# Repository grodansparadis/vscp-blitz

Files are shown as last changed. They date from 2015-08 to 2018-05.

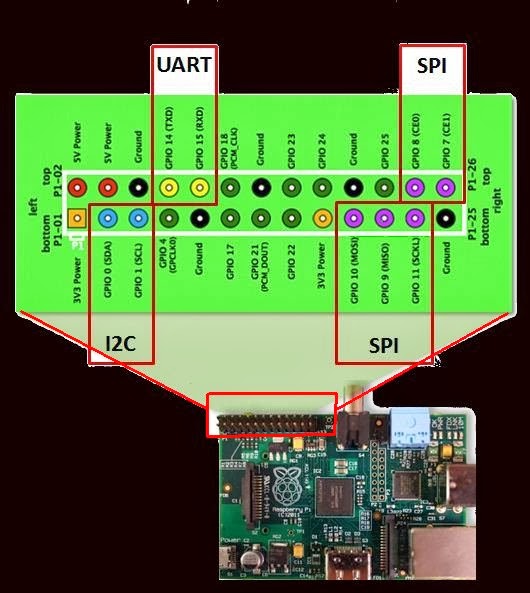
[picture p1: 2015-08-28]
docs/GPIO_pinout_raspberry_pi_v1.jpg

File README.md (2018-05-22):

# Blitz
Wifi + Ethernet + CAN board for VSCP

<hr>

This project is part of the <a href="http://www.vscp.org">VSCP (Very Simple Control Protocol) project</a>. 

<hr>

This project is licensed under the 
<a href="http://creativecommons.org/licenses/by-nc-sa/3.0/">Creative Commons open source license Attribution-NonCommercial-ShareAlike 3.0 Unported</a>. 
Other license options are available by conacting <a href="malto:info@grodansparadis.com">Paradis of the Frog AB</a>

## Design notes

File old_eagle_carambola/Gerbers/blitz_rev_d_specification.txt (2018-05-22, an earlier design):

Ake Hedman <akhe@grodansparadis.com>
Grodans Paradis AB

Date:				2014-06-18
Part Number: 		Blitz
Number of boards: 	120
Number of layers: 	2
Material: 			FR4
Final Thickness:	1.6 mm
Final copper:		1/1oz
Surface treatment: 	ENIG
Unit Size:			72x110
Panel Size:		
Unit/panel:			4
Solder Mask:		Black
Silk Screen: 		White	
Outline Profile:	CNC Routing + V-cut
X-out Allowed:		1
Stencil needed:		yes
Gerber layer for Stencil: Component Cream (pmc)

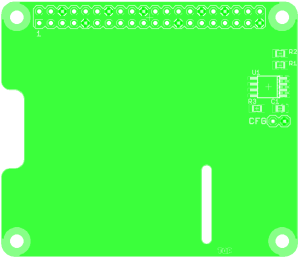
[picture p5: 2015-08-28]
docs/RasPi-BplusHAT.png

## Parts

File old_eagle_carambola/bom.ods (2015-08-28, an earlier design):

Partl | ist exported from C:/U | sers/akhe/Documents/d | evelopment/hardware | _zeus/wifi/carambola/blitz/eagle/blitz.sch at 2011-10-05 18:25:48
Part | Value | Device | Package | Description | Description | Supplier | Partnumber | Price
C1 | 4.7nF | C-EUC0805 | C0805 | CAPACITOR, European symbol | 4.7nF Cheramic capacitor | Bejoken | 522508 | 0,05
C2 | 4.7nF | C-EUC0805 | C0805 | CAPACITOR, European symbol | 4.7nF Cheramic capacitor | Bejoken | 522508 | 0,05
C3 | 2.2UF 50V | C-EUC2012 | C2012 | CAPACITOR, European symbol | Capacity | Digikey | 445-3464-1-ND | 2,4
C4 | 220uF/10V | CPOL-EUSMCC | SMC_C | POLARIZED CAPACITOR, European symbol | Capacitor SMD | Digikey | 399-5168-1-nd | 12,56
C5 | 220uF/10V | CPOL-EUSMCC | SMC_C | POLARIZED CAPACITOR, European symbol | Capacitor SMD | Digikey | 399-5168-1-nd | 12,56
C6 | 100n | C-EUC0805 | C0805 | CAPACITOR, European symbol | 100nF Cheramic capacitor | Bejoken | 522526 | 0,07
C7 | 100n | C-EUC0805 | C0805 | CAPACITOR, European symbol | 100nF Cheramic capacitor | Bejoken | 522526 | 0,07
C8 | 15pF | C-EUC0805 | C0805 | CAPACITOR, European symbol | Kondensator | Bejoken | 522419 | 0,11
C9 | 15pF | C-EUC0805 | C0805 | CAPACITOR, European symbol | Kondensator | Bejoken | 522419 | 0,11
C10 | 100nF | C-EUC0805 | C0805 | CAPACITOR, European symbol | Avkopplingskondensator | Bejoken | 522526 | 0,07
C11 | 100nF | C-EUC0805 | C0805 | CAPACITOR, European symbol | Avkopplingskondensator | Bejoken | 522526 | 0,07
C12 | 100nF | C-EUC0805 | C0805 | CAPACITOR, European symbol | Avkopplingskondensator | Bejoken | 522526 | 0,07
C13 | 22pF | C-EUC0805 | C0805 | CAPACITOR, European symbol | 22pF Cheramic capacitor | Bejoken | 522423 | 0,11
C14 | 22pF | C-EUC0805 | C0805 | CAPACITOR, European symbol | 22pF Cheramic capacitor | Bejoken | 522423 | 0,11
C15 | 100n | C-EUC0805 | C0805 | CAPACITOR, European symbol | 100nF Cheramic capacitor | Bejoken | 522526 | 0,07
C16 | 4.7nF | C-EUC0805 | C0805 | CAPACITOR, European symbol | 4.7nF Cheramic capacitor | Bejoken | 522508 | 0,05
C17 | 4.7nF | C-EUC0805 | C0805 | CAPACITOR, European symbol | 4.7nF Cheramic capacitor | Bejoken | 522508 | 0,05
C18 | 2.2UF 50V | C-EUC2012 | C2012 | CAPACITOR, European symbol | Capacity | Digikey | 445-3464-1-ND | 2,4
C19 | 220uF/10V | CPOL-EUSMCC | SMC_C | POLARIZED CAPACITOR, European symbol | Capacitor SMD | Digikey | 399-5168-1-nd | 12,56
C20 | 220uF/10V | CPOL-EUSMCC | SMC_C | POLARIZED CAPACITOR, European symbol | Capacitor SMD | Digikey | 399-5168-1-nd | 12,56
C21 | 100nF | C-EUC0805 | C0805 | CAPACITOR, European symbol | Avkopplingskondensator | Bejoken | 522526 | 0,07
C22 | 100nF | C-EUC0805 | C0805 | CAPACITOR, European symbol | Avkopplingskondensator | Bejoken | 522526 | 0,07
C23 | 100n | C-EUC0805 | C0805 | CAPACITOR, European symbol | 100nF Cheramic capacitor | Bejoken | 522526 | 0,07
C24 | 100n | C-EUC0805 | C0805 | CAPACITOR, European symbol | 100nF Cheramic capacitor | Bejoken | 522526 | 0,07
C25 | 100n | C-EUC0805 | C0805 | CAPACITOR, European symbol | 100nF Cheramic capacitor | Bejoken | 522526 | 0,07
C26 | 2.2uF | C-EUC2012 | C2012 | CAPACITOR, European symbol | Capacitor | Digikey | 445-3464-1-ND | 2,4
C27 | 100n | C-EUC0805 | C0805 | CAPACITOR, European symbol | 100nF Cheramic capacitor | Bejoken | 522526 | 0,07
C28 | 100n | C-EUC0805 | C0805 | CAPACITOR, European symbol | 100nF Cheramic capacitor | Bejoken | 522526 | 0,07
C29 | 100n | C-EUC0805 | C0805 | CAPACITOR, European symbol | 100nF Cheramic capacitor | Bejoken | 522526 | 0,07
D1 | 1N5819 | 1N5819 | SOD-123 |  | Schotty diod | Digikey | 1n5819hw-fdict-nd | 3,84
D2 | NUP2105L | DIODE-2CA|ACSOT23 | SOT23 | Dual DIODE Cathode-Anode|Anode-Cathode | Tansient protection | Digikey | NUP2105LT1GOSCT-ND | 4
D3 | LED yellow | LED_2012 | C2012 |  | Gul LED | Digikey | 475-1410-1-nd | 0,88
D4 | LED Green | LED_2012 | C2012 |  | Grön LED | Digikey | 475-1410-1-nd | 0,88
D5 | 1N5819 | 1N5819 | SOD-123 |  | Schotty diod | Digikey | 1n5819hw-fdict-nd | 3,84
D6 | LED Red | LED_2012 | C2012 |  | LED röd | Digikey | 475-1415-1-ND | 0,88
H1 | Antenna | SPECIAL_DRILL_0.1000 | PAD_0.1000 | Special drills |  |  |  | 0
IC1 | BD9001F | BD9001F | SOP8 |  | Swithing regulator | Digikey | BD9001F-E2CT-ND | 39,84
IC2 | MCP2515 | MCP2515 | SO-18W |  | CAN Controller | Digikey | MCP2515-I/SO-ND | 15,84
IC3 | SN65HVD232 | MCP2551SN | SO-08 | High Speed CAN tranceiver | 3.3V CAN tranceiver | Digikey | 296-15381-1-ND | 26,05
IC4 | BD9001F | BD9001F | SOP8 |  | Swithing regulator | Digikey | BD9001F-E2CT-ND | 39,84
IC5 | PIC18F26K20 | PIC18F26K20 | SSOP28 |  | Processor | Digikey | PIC18F26K20-I/SS-ND | 20,98
IC6 | 11AA02E48 | 11AA02E48 | SOT23 |  | MAC Address | Digikey | 11aa02e48t-i/ttct-nd | 4
IC7 | 11AA02E48 | 11AA02E48 | SOT23 |  | MAC Address | Digikey | 11aa02e48t-i/ttct-nd | 4
IC8 | CARAMBOLA | CARAMBOLA | CARAMBOLA |  | Linux ;odule | 8Devices | x1 | 200
J1 | 22-23-2021 | 22-23-2021 | 22-23-2021 | .100" (2.54mm) Center Header - 2 Pin | Enkel stiftlist | Digikey | SAM1035-50-ND | 0,33
J2 | A00-108-220-450 | A00-108-220-450 | RJ-45 |  | RJ-45 connector | Digikey | 151-1099-nd | 5,6
J3 | MICROSD_SPI_MODE | MICROSD_SPI_MODE | MICRO_SD_CONNECTOR | MOLEX - 49225-0821 - CONNECTEUR MICRO SD PUSH/PUSH REVFabricant: MOLEXCode commande Farnell: 1366700Référence fabricant: 49225-0821 | SD Connector | Digikey | WM3295ct-ND | 33,36
J4 | USB-B-S | USB-B-S | USB-B-SMT | USB Connectors | USB B connector | Digikey | ED2994-ND | 8,8
J5 |  | MA03-1 | MA03-1 | PIN HEADER | Enkel stiftlist | Digikey | SAM1035-50-ND | 0,33
J6 |  | MA03-1 | MA03-1 | PIN HEADER | Enkel stiftlist | Digikey | SAM1035-50-ND | 0,33
J7 |  | MA08-1 | MA08-1 | PIN HEADER | Enkel Stiftlist | Digikey | SAM1035-50-ND | 0,33
J8 | TAIMAGRPJ-003TC1 | TAIMAGRPJ-003TC1 | TAIMAGRJP-003TC1 |  | Ethernet Trafo | Tysk | RPC | 40
JP2 | TX433_3V_MODULE | TX433_3V_MODULE | FOUR |  | Transmitter 433MHz | Electrokit | 41004048 | 44,5
JP4 | Programming connector | MA06-1 | MA06-1 | PIN HEADER | Enkel stiftlist | Digikey | SAM1035-50-ND | 0,33
L1 | NR10050T470M | NR10050T470M | NR10050T470M |  | Inductance | Digikey | 587-1700-1-ND | 7,52
L2 | NR10050T470M | NR10050T470M | NR10050T470M |  | Inductance | Digikey | 587-1700-1-ND | 7,52
L3 | FERRITE-BEAD | FERRITE-BEAD | 805 |  | Ferrite | Digikey | 445-1568-1-nd | 2,88
Q1 | 12 MHZ | HC-49S | 9C | Digikey 887-1050-1-nd | Crystal | Digikey | 887-1053-1-ND | 2,56
R1 | 150k | R-EU_M0805 | M0805 | RESISTOR, European symbol | Resistor | Bejoken | 454710 | 0,01
R2 | 150k | R-EU_M0805 | M0805 | RESISTOR, European symbol | Resistor | Bejoken | 454710 | 0,01
R3 | 39k/1% | R-EU_M0805 | M0805 | RESISTOR, European symbol | Resistor | Bejoken | 454690 | 0,01
R4 | 10K/1% | R-EU_M0805 | M0805 | RESISTOR, European symbol | Resistor | Bejoken | 454676 | 0,01
R5 | 330 | R-EU_M0805 | M0805 | RESISTOR, European symbol | Resistor | Bejoken | 454636 | 0,01
R6 | 10k | R-EU_M0805 | M0805 | RESISTOR, European symbol | Resistor | Bejoken | 454676 | 0,01
R9 | 10K | R-EU_R0805 | R0805 | RESISTOR, European symbol | Resistor | Bejoken | 454676 | 0,01
R10 | 10K | R-EU_R0805 | R0805 | RESISTOR, European symbol | Resistor | Bejoken | 454676 | 0,01
R11 | 150k | R-EU_M0805 | M0805 | RESISTOR, European symbol | Resistor | Bejoken | 454710 | 0,01
R12 | 150k | R-EU_M0805 | M0805 | RESISTOR, European symbol | Resistor | Bejoken | 454710 | 0,01
R13 | 4.3k/1% | R-EU_M0805 | M0805 | RESISTOR, European symbol | Resistor | Digikey | 311-4.30KCRTR-ND | 0,02
R14 | 1.8K/1% | R-EU_M0805 | M0805 | RESISTOR, European symbol | Resistor | Bejoken | 454658 | 0,01
R15 | 49.9/1% | R-EU_M0805 | M0805 | RESISTOR, European symbol | Resistor | Digikey | 311-49.9CRTR-ND | 0,02
R16 | 49.9/1% | R-EU_M0805 | M0805 | RESISTOR, European symbol | Resistor | Digikey | 311-49.9CRTR-ND | 0,02
R17 | 49.9/1% | R-EU_M0805 | M0805 | RESISTOR, European symbol | Resistor | Digikey | 311-49.9CRTR-ND | 0,02
R18 | 49.9/1% | R-EU_M0805 | M0805 | RESISTOR, European symbol | Resistor | Digikey | 311-49.9CRTR-ND | 0,02
R19 | 120r | R-EU_R0805 | R0805 | RESISTOR, European symbol | Resistor | Bejoken | 454626 | 0,01
R20 | 1M | R-EU_M0805 | M0805 | RESISTOR, European symbol | Resistor | Bejoken | 454742 | 0,01
R21 | 330 | R-EU_M0805 | M0805 | RESISTOR, European symbol | Resistor | Bejoken | 454636 | 0,01
R22 | 330 | R-EU_M0805 | M0805 | RESISTOR, European symbol | Resistor | Bejoken | 454636 | 0,01
R23 | 10k | R-EU_M0805 | M0805 | RESISTOR, European symbol | Resistor | Bejoken | 454676 | 0,01
R24 | 330 | R-EU_M0805 | M0805 | RESISTOR, European symbol | Resistor | Bejoken | 454636 | 0,01
X1 | TXC-7V-SERIES 8 MHz | TXC-7V-SERIES | TXC-7V-SERIES |  | Kristall | Digokey | 887-1452-1-nd | 8,18
Z1 | 1N4731(4.3V) | 1N4731(4.3V) | 1N4731 |  | Zener | Digikey | 1n4731A-tpct-nd | 3,6
Z2 | 1N4731(4.3V) | 1N4731(4.3V) | 1N4731 |  | Zener | Digikey | 1n4731A-tpct-nd | 3,6
 |  |  |  |  |  |  |  | 594,02

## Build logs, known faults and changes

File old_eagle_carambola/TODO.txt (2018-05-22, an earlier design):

Add PoE Ag9400 - https://www.semiconductorstore.com/pages/asp/DownloadDirect.asp?sid=1401505158572

Add Power connector instead of SD card.

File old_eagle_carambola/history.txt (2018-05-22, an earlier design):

Blitz
=====

2014-06-04 - AKHE Fixed dimensions.
2014-06-04 - AKHE Ready for factory
2014-06-04 - AKHE Rev D
2014-04-11 - AKHE Changed crystal to 10MHz

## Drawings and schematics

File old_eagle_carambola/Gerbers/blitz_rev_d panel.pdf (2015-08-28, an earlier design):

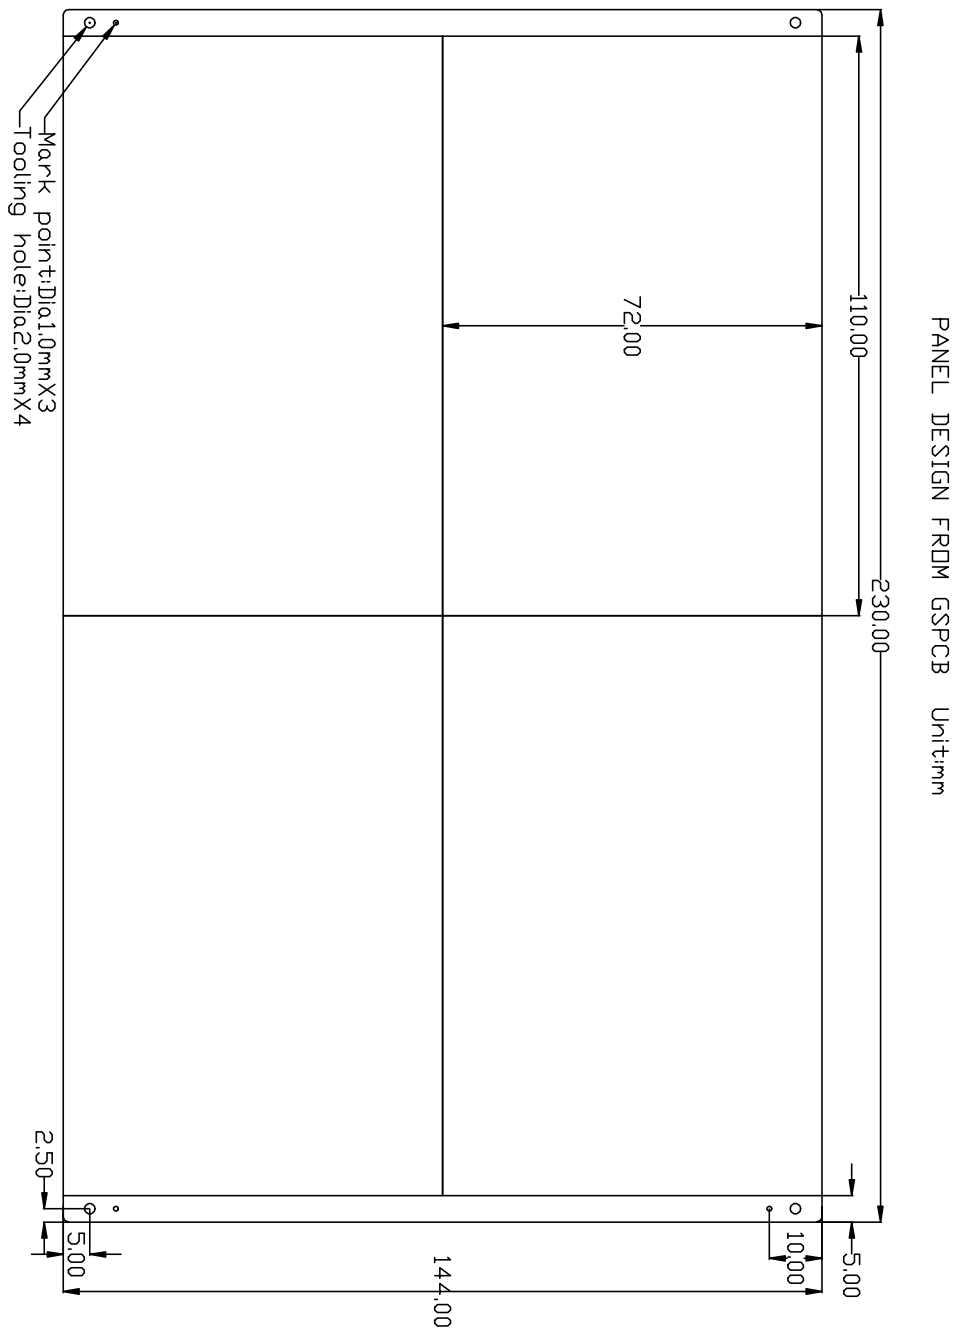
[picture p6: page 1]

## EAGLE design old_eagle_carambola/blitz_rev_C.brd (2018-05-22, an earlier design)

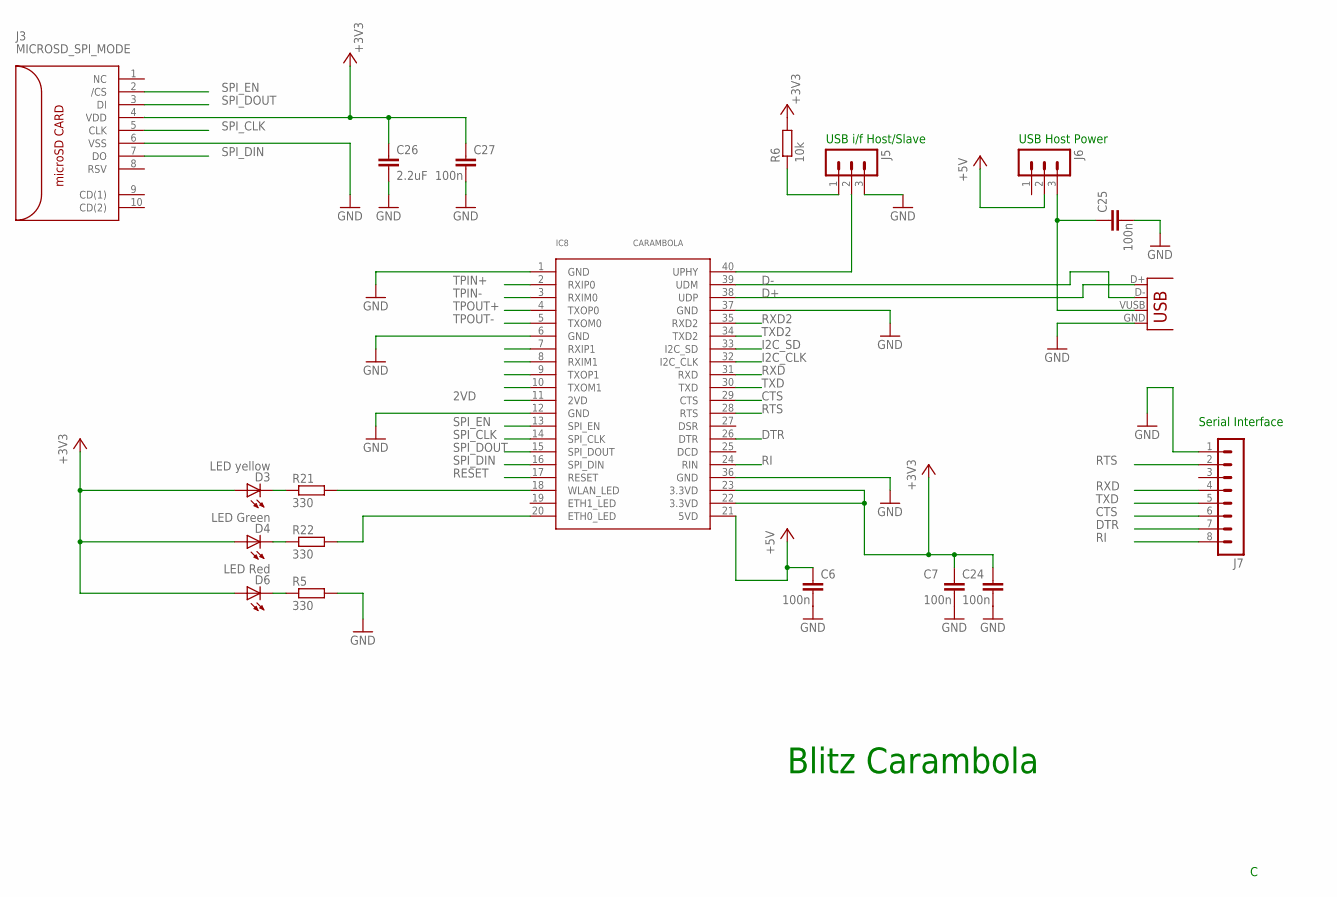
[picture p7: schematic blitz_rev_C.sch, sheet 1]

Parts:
C6, C7, C24, C25, C27: 100n; C0805
C26: 2.2uF; C2012
D3: LED yellow; C2012
D4: LED Green; C2012
D6: LED Red; C2012
IC8: CARAMBOLA
J3: MICROSD_SPI_MODE; MICRO_SD_CONNECTOR
J4: USB-B-S; USB-B-SMT
J5, J6: MA03-1
J7: MA08-1
R5, R21, R22: 330; M0805
R6: 10k; M0805

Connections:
2VD: IC8.11 (2VD)
+3V3: C7.1, C24.1, C26.1, C27.1, D3.1 (A), D4.1 (A), D6.1 (A), IC8.22 (3.3VD), IC8.23 (3.3VD), J3.4 (VDD), R6.2; also elsewhere on the board
+5V: C6.1, IC8.21 (5VD), J6.2; also elsewhere on the board
CTS: IC8.29 (CTS), J7.6
D+: IC8.38 (UDP), J4.D+
D-: IC8.39 (UDM), J4.D-
DTR: IC8.26 (DTR), J7.7
GND: C6.2, C7.2, C24.2, C25.2, C26.2, C27.2, IC8.1 (GND), IC8.6 (GND), IC8.12 (GND), IC8.36 (GND), IC8.37 (GND), J3.6 (VSS), J4.GND, J5.3, J7.1, R5.2; also elsewhere on the board
I2C_CLK: IC8.32 (I2C_CLK)
I2C_SD: IC8.33 (I2C_SD)
unnamed: J5.1, R6.1
unnamed: C25.1, J4.VUSB (VBUS), J6.3
unnamed: D4.2 (C), R22.1
unnamed: D3.2 (C), R21.1
unnamed: IC8.18 (WLAN_LED), R21.2
unnamed: IC8.20 (ETH0_LED), R22.2
unnamed: D6.2 (C), R5.1
unnamed: IC8.40 (UPHY), J5.2
RESET: IC8.17 (RESET)
RI: IC8.24 (RIN), J7.8
RTS: IC8.28 (RTS), J7.2
RXD: IC8.31 (RXD), J7.4
RXD2: IC8.35 (RXD2); also elsewhere on the board
SPI_CLK: IC8.14 (SPI_CLK), J3.5 (CLK)
SPI_DIN: IC8.16 (SPI_DIN), J3.7 (DO)
SPI_DOUT: IC8.15 (SPI_DOUT), J3.3 (DI)
SPI_EN: IC8.13 (SPI_EN), J3.2 (/CS)
TPIN+: IC8.2 (RXIP0); also elsewhere on the board
TPIN-: IC8.3 (RXIM0); also elsewhere on the board
TPOUT+: IC8.4 (TXOP0); also elsewhere on the board
TPOUT-: IC8.5 (TXOM0); also elsewhere on the board
TXD: IC8.30 (TXD), J7.5
TXD2: IC8.34 (TXD2); also elsewhere on the board

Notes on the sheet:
Blitz Carambola
USB i/f Host/Slave
USB Host Power
Serial Interface

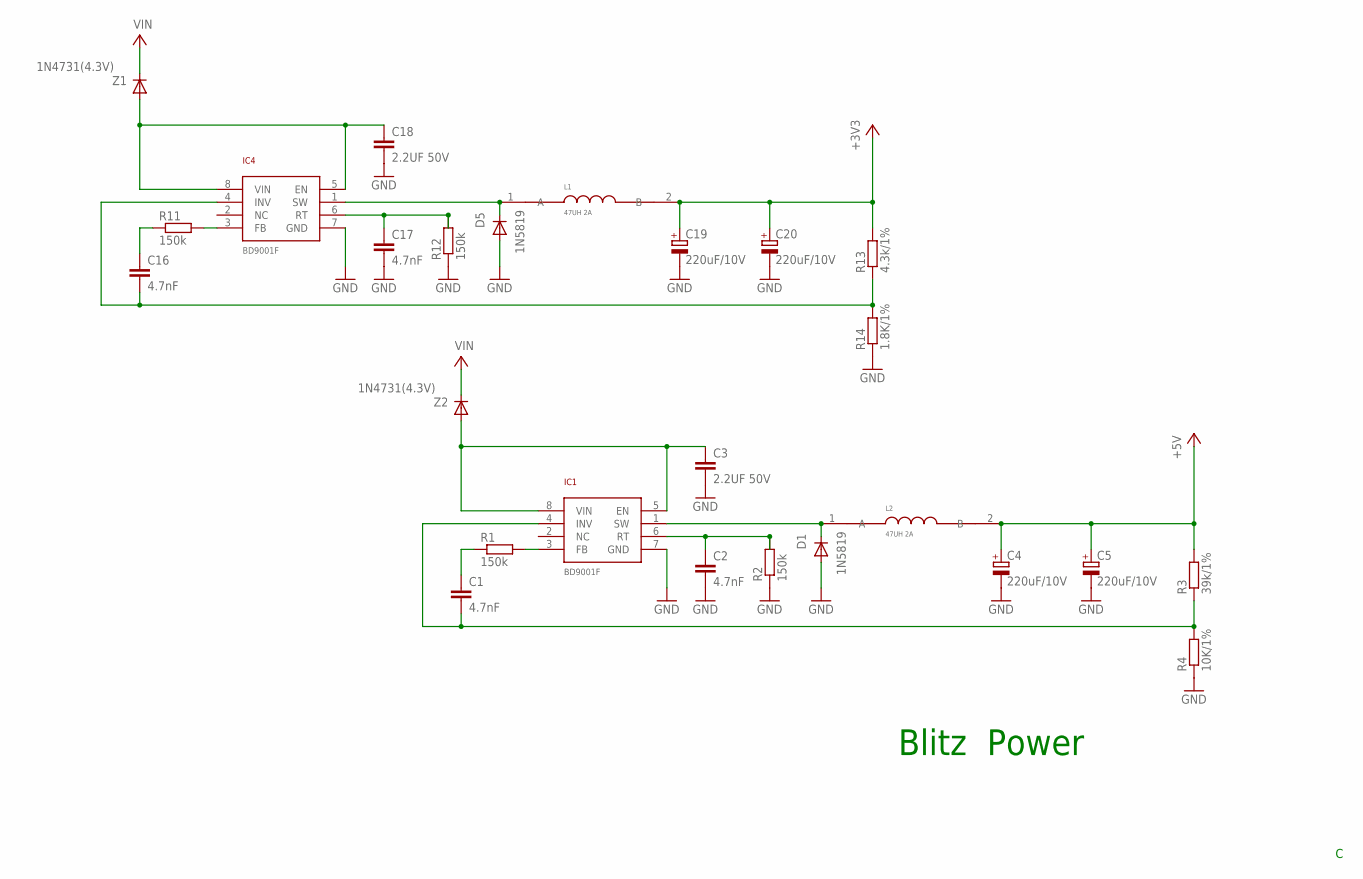
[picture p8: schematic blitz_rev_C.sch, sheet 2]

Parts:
C1, C2, C16, C17: 4.7nF; C0805
C3, C18: 2.2UF 50V; C2012
C4, C5, C19, C20: 220uF/10V; SMC_C
D1, D5: 1N5819; SOD-123
IC1, IC4: BD9001F; SOP8
L1, L2: 47UH 2A; NR10050T470M
R1, R2, R11, R12: 150k; M0805
R3: 39k/1%; M0805
R4: 10K/1%; M0805
R13: 4.3k/1%; M0805
R14: 1.8K/1%; M0805
Z1, Z2: 1N4731(4.3V); 1N4731

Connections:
+3V3: C19.+, C20.+, L1.2 (B), R13.2; also elsewhere on the board
+5V: C4.+, C5.+, L2.2 (B), R3.2; also elsewhere on the board
GND: C2.2, C3.2, C4.-, C5.-, C17.2, C18.2, C19.-, C20.-, D1.A, D5.A, IC1.7 (GND), IC4.7 (GND), R2.1, R4.1, R12.1, R14.1; also elsewhere on the board
unnamed: IC1.3 (FB), R1.2
unnamed: C1.1, R1.1
unnamed: C1.2, IC1.4 (INV), R3.1, R4.2
unnamed: C2.1, IC1.6 (RT), R2.2
unnamed: C3.1, IC1.5 (EN), IC1.8 (VIN), Z2.A
unnamed: D1.C, IC1.1 (SW), L2.1 (A)
unnamed: IC4.3 (FB), R11.2
unnamed: C16.1, R11.1
unnamed: C16.2, IC4.4 (INV), R13.1, R14.2
unnamed: C17.1, IC4.6 (RT), R12.2
unnamed: C18.1, IC4.5 (EN), IC4.8 (VIN), Z1.A
unnamed: D5.C, IC4.1 (SW), L1.1 (A)
V+: Z1.C, Z2.C; also elsewhere on the board

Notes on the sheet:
Blitz Power

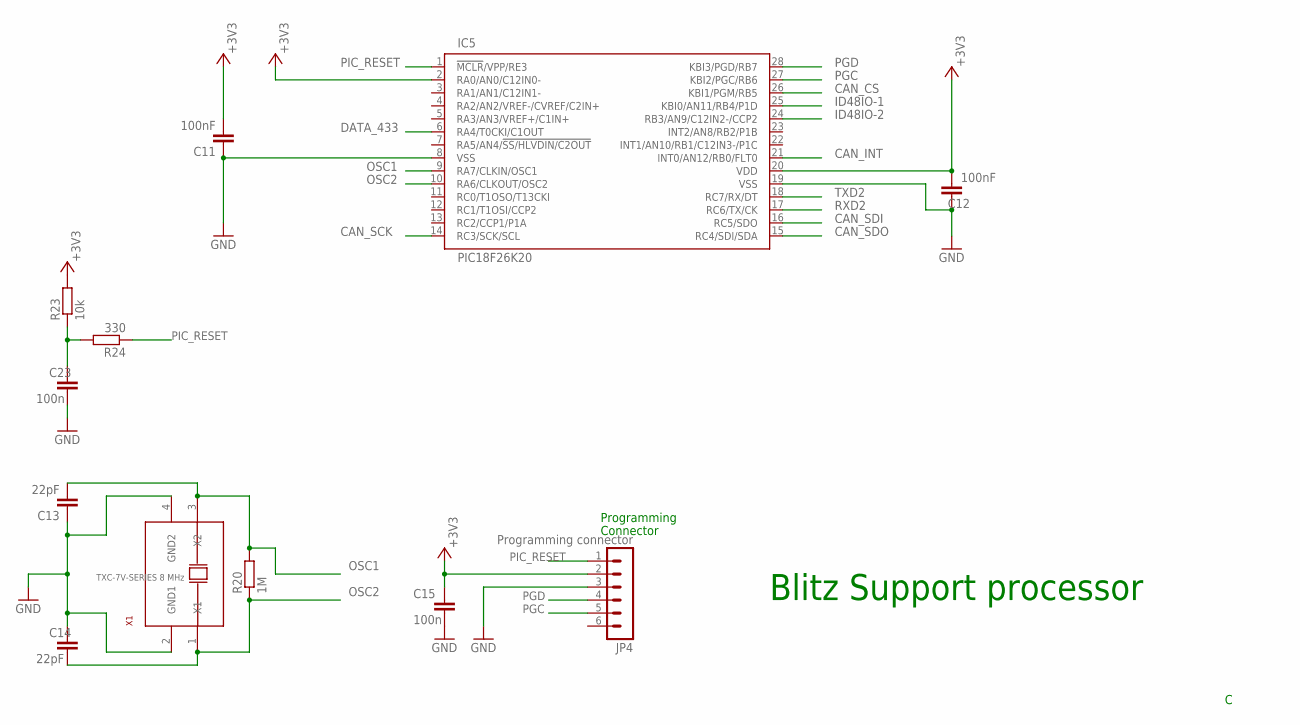
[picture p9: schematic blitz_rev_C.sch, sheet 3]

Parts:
C11, C12: 100nF; C0805
C13, C14: 22pF; C0805
C15, C23: 100n; C0805
IC5: PIC18F26K20; SSOP28
JP4: Programming connector; MA06-1
R20: 1M; M0805
R23: 10k; M0805
R24: 330; M0805
X1: TXC-7V-SERIES 8 MHz; TXC-7V-SERIES

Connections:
+3V3: C11.2, C12.2, C15.1, IC5.2 (RA0/AN0/C12IN0-), IC5.20 (VDD), JP4.2, R23.2; also elsewhere on the board
CAN_CS: IC5.26 (KBI1/PGM/RB5); also elsewhere on the board
CAN_INT: IC5.21 (INT0/AN12/RB0/FLT0); also elsewhere on the board
CAN_SCK: IC5.14 (RC3/SCK/SCL); also elsewhere on the board
CAN_SDI: IC5.16 (RC5/SDO); also elsewhere on the board
CAN_SDO: IC5.15 (RC4/SDI/SDA); also elsewhere on the board
DATA_433: IC5.6 (RA4/T0CKI/C1OUT); also elsewhere on the board
GND: C11.1, C12.1, C13.1, C14.1, C15.2, C23.2, IC5.8 (VSS), IC5.19 (VSS), JP4.3, X1.2 (GND1), X1.4 (GND2); also elsewhere on the board
ID48IO-1: IC5.25 (KBI0/AN11/RB4/P1D); also elsewhere on the board
ID48IO-2: IC5.24 (RB3/AN9/C12IN2-/CCP2); also elsewhere on the board
unnamed: C23.1, R23.1, R24.2
OSC1: C13.2, IC5.9 (RA7/CLKIN/OSC1), R20.2, X1.3 (X2)
OSC2: C14.2, IC5.10 (RA6/CLKOUT/OSC2), R20.1, X1.1 (X1)
PGC: IC5.27 (KBI2/PGC/RB6), JP4.5
PGD: IC5.28 (KBI3/PGD/RB7), JP4.4
PIC_RESET: IC5.1 (!MCLR!/VPP/RE3), JP4.1, R24.1
RXD2: IC5.17 (RC6/TX/CK); also elsewhere on the board
TXD2: IC5.18 (RC7/RX/DT); also elsewhere on the board

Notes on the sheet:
Programming
Connector
Blitz Support processor

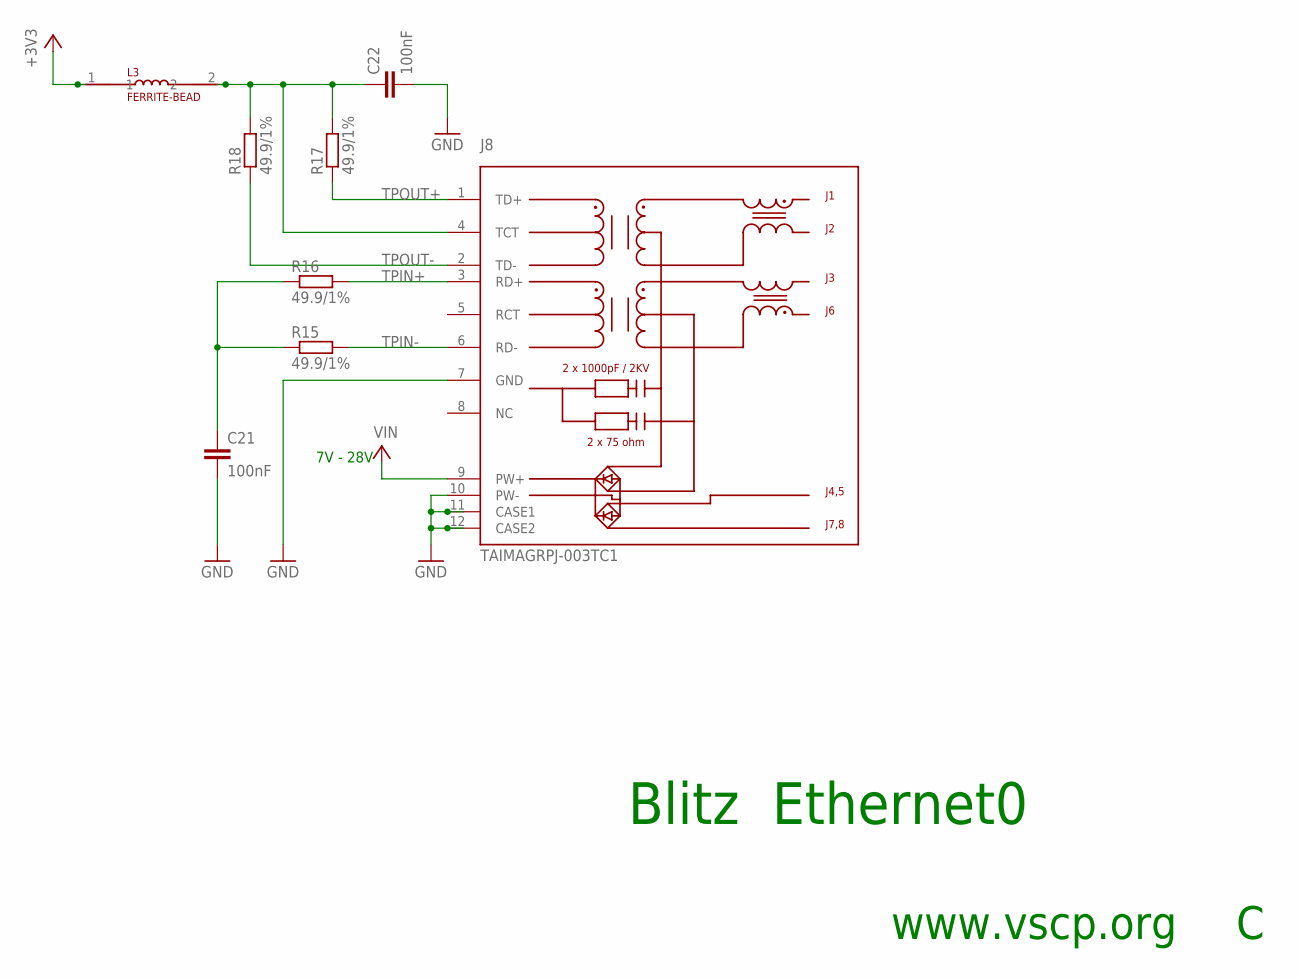
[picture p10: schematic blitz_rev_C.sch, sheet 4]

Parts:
C21, C22: 100nF; C0805
J8: TAIMAGRPJ-003TC1; TAIMAGRJP-003TC1
L3: FERRITE-BEAD; 0805
R15, R16, R17, R18: 49.9/1%; M0805

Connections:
+3V3: L3.1; also elsewhere on the board
GND: C21.2, C22.2, J8.7 (GND), J8.10 (PW-), J8.11 (CASE1), J8.12 (CASE2); also elsewhere on the board
unnamed: C21.1, R15.1, R16.1
unnamed: C22.1, J8.4 (TCT), L3.2, R17.2, R18.2
TPIN+: J8.3 (RD+), R16.2; also elsewhere on the board
TPIN-: J8.6 (RD-), R15.2; also elsewhere on the board
TPOUT+: J8.1 (TD+), R17.1; also elsewhere on the board
TPOUT-: J8.2 (TD-), R18.1; also elsewhere on the board
V+: J8.9 (PW+); also elsewhere on the board

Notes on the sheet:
Blitz Ethernet0
7V - 28V
www.vscp.org

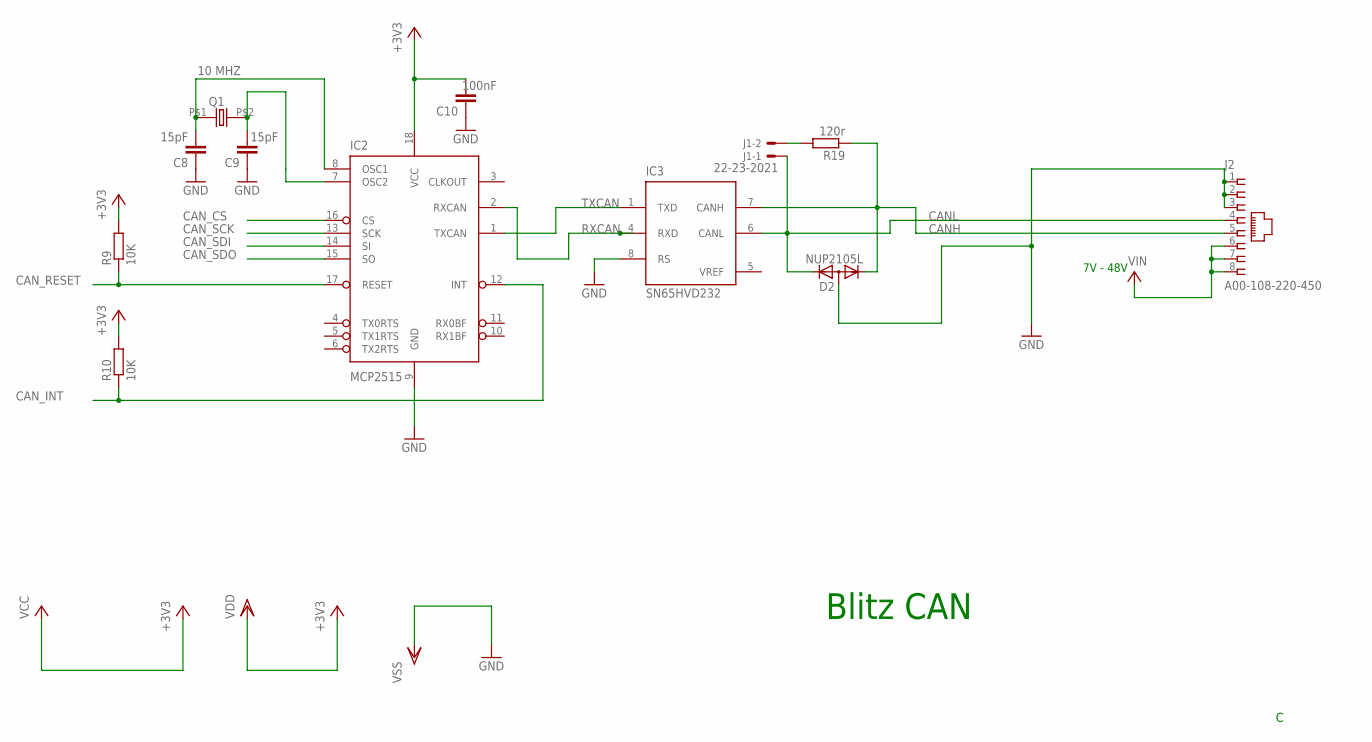
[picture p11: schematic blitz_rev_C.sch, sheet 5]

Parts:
C8, C9: 15pF; C0805
C10: 100nF; C0805
D2: NUP2105L; SOT23
IC2: MCP2515; SO-18W
IC3: SN65HVD232; SO-08
J1: 22-23-2021
J2: A00-108-220-450; RJ-45
Q1: 10 MHZ; 9C
R9, R10: 10K; R0805
R19: 120r; R0805

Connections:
+3V3: C10.2, IC2.18 (VCC), IC3.3 (VDD), R9.2, R10.2; also elsewhere on the board
CANH: D2.1 (K1), IC3.7 (CANH), J2.5, R19.1
CANL: D2.2 (K2), IC3.6 (CANL), J1.1, J2.4
CAN_CS: IC2.16 (CS); also elsewhere on the board
CAN_INT: IC2.12 (INT), R10.1; also elsewhere on the board
CAN_RESET: IC2.17 (RESET), R9.1
CAN_SCK: IC2.13 (SCK); also elsewhere on the board
CAN_SDI: IC2.14 (SI); also elsewhere on the board
CAN_SDO: IC2.15 (SO); also elsewhere on the board
GND: C8.1, C9.1, C10.1, D2.3 (A), IC2.9 (GND), IC3.2 (VSS), IC3.8 (RS), J2.1, J2.2, J2.3; also elsewhere on the board
unnamed: C8.2, IC2.8 (OSC1), Q1.P$1 (1)
unnamed: C9.2, IC2.7 (OSC2), Q1.P$2 (2)
unnamed: J1.2, R19.2
RXCAN: IC2.2 (RXCAN), IC3.4 (RXD)
TXCAN: IC2.1 (TXCAN), IC3.1 (TXD)
V+: J2.6, J2.7, J2.8; also elsewhere on the board
VREF: IC3.5 (VREF)

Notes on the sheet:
Blitz CAN
7V - 48V

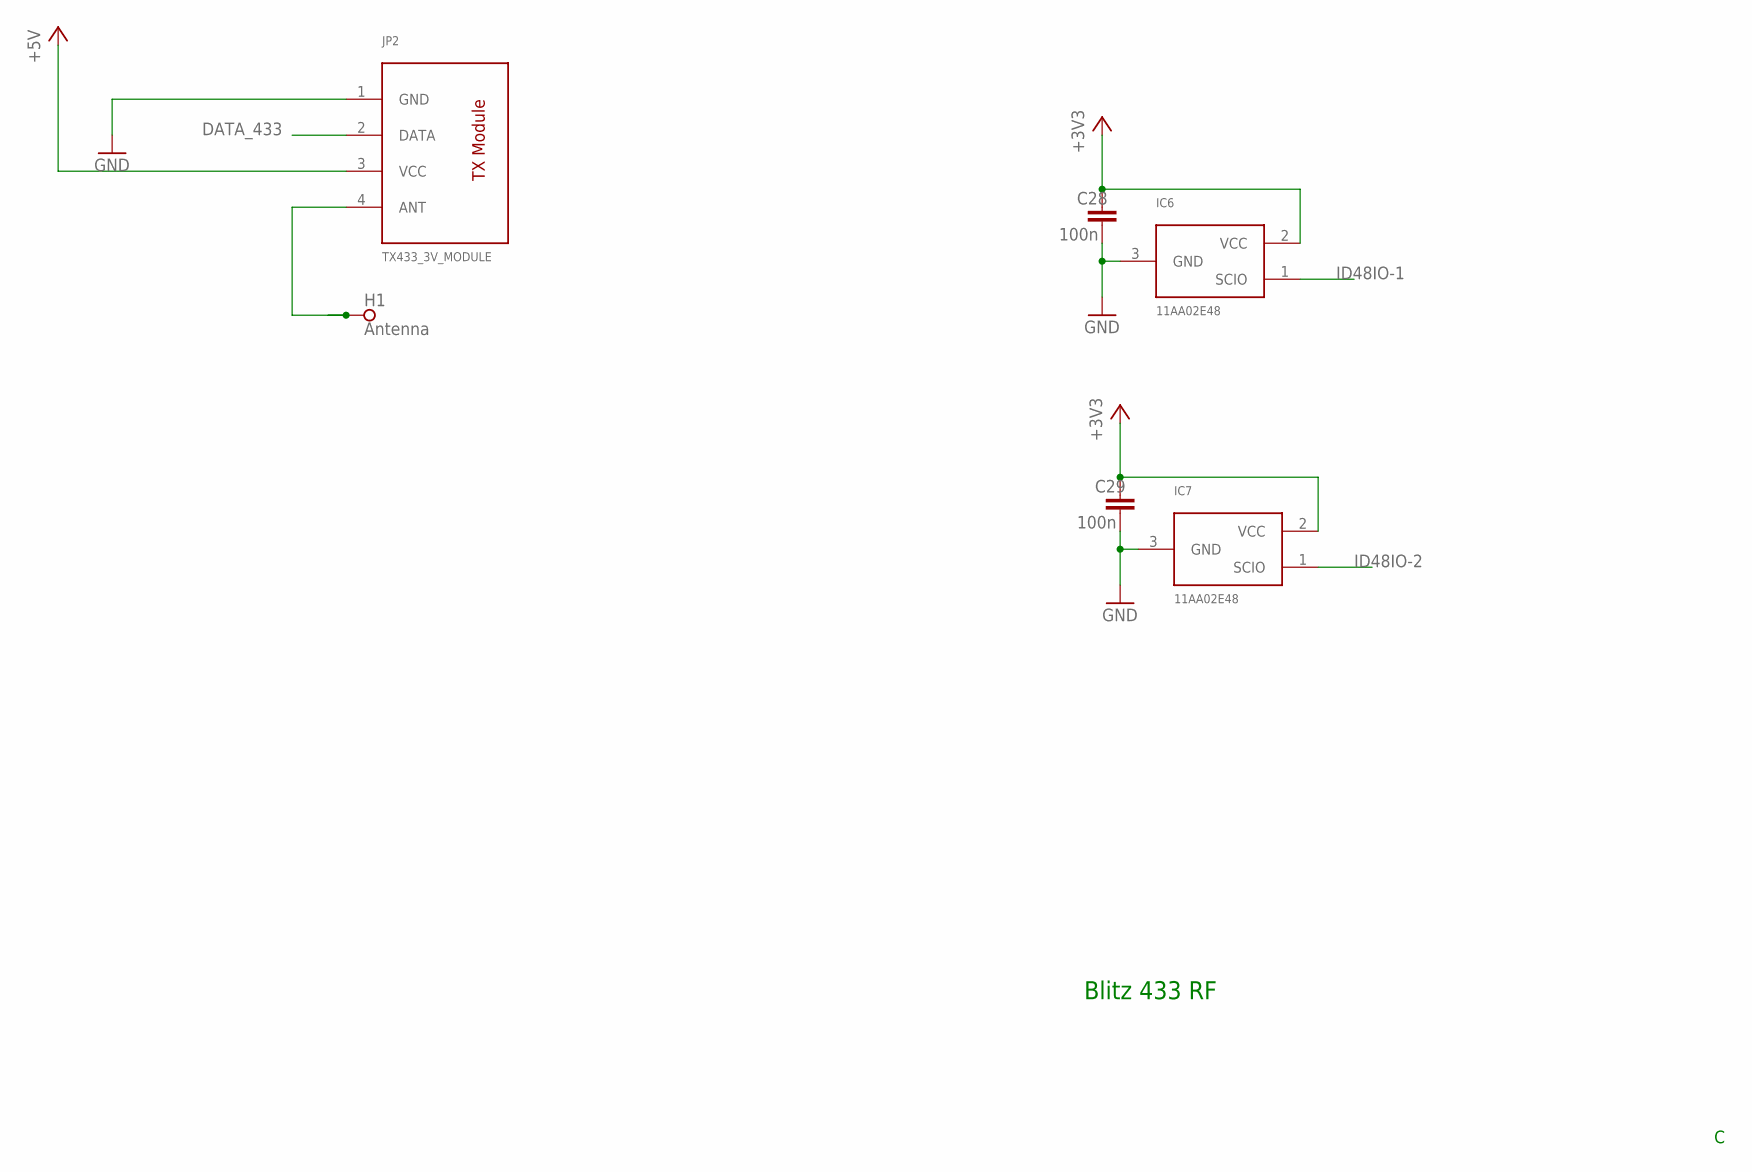
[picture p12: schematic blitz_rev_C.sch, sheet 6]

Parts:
C28, C29: 100n; C0805
H1: Antenna; PAD_0.1000
IC6, IC7: 11AA02E48; SOT23
JP2: TX433_3V_MODULE; FOUR

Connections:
+3V3: C28.1, C29.1, IC6.2 (VCC), IC7.2 (VCC); also elsewhere on the board
+5V: JP2.3 (VCC); also elsewhere on the board
ANT: H1.1, JP2.4 (ANT)
DATA_433: JP2.2 (DATA); also elsewhere on the board
GND: C28.2, C29.2, IC6.3 (GND), IC7.3 (GND), JP2.1 (GND); also elsewhere on the board
ID48IO-1: IC6.1 (SCIO); also elsewhere on the board
ID48IO-2: IC7.1 (SCIO); also elsewhere on the board

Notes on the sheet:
Blitz 433 RF

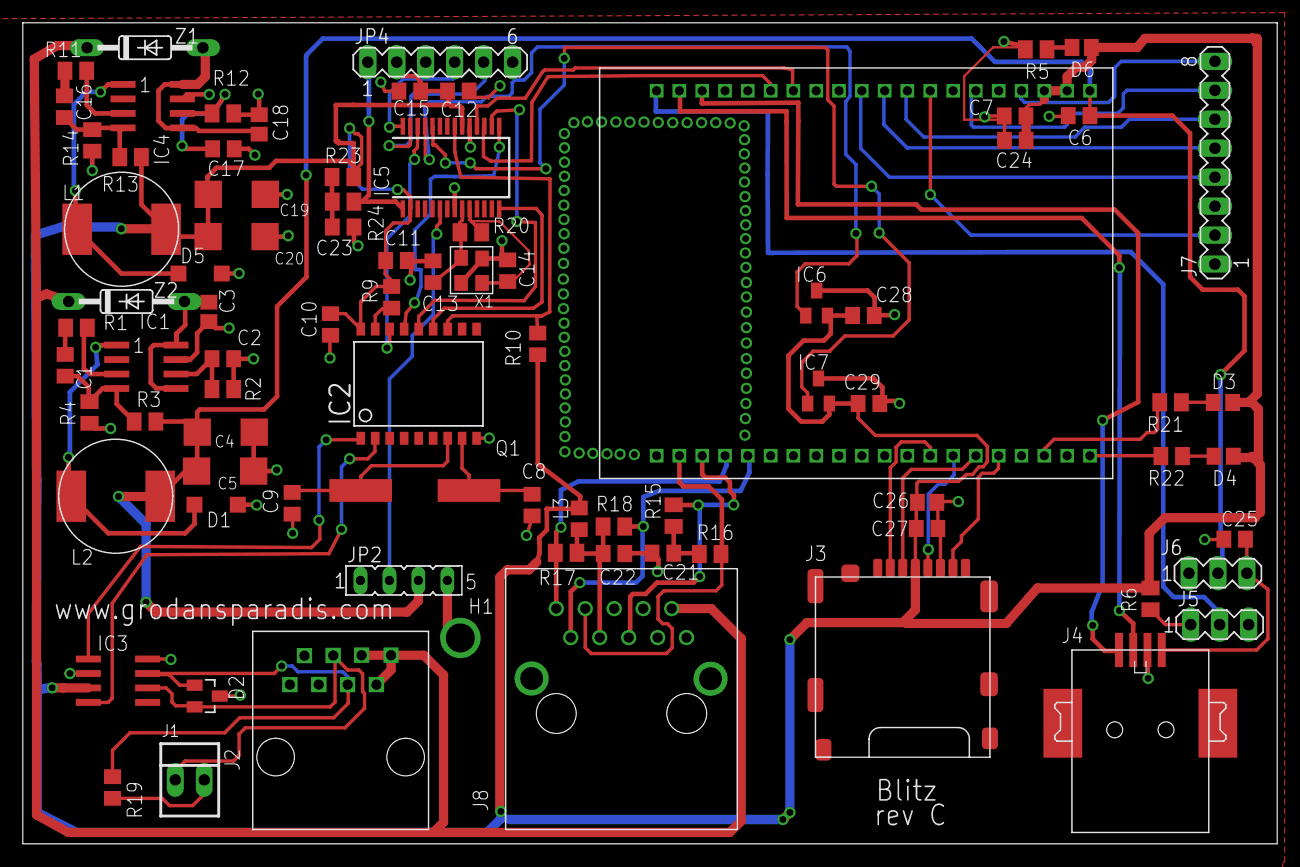
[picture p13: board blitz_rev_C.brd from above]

Board: 2 copper layers, 110.0 x 72.0 mm, 83 parts (0 on the bottom side), 67 nets.

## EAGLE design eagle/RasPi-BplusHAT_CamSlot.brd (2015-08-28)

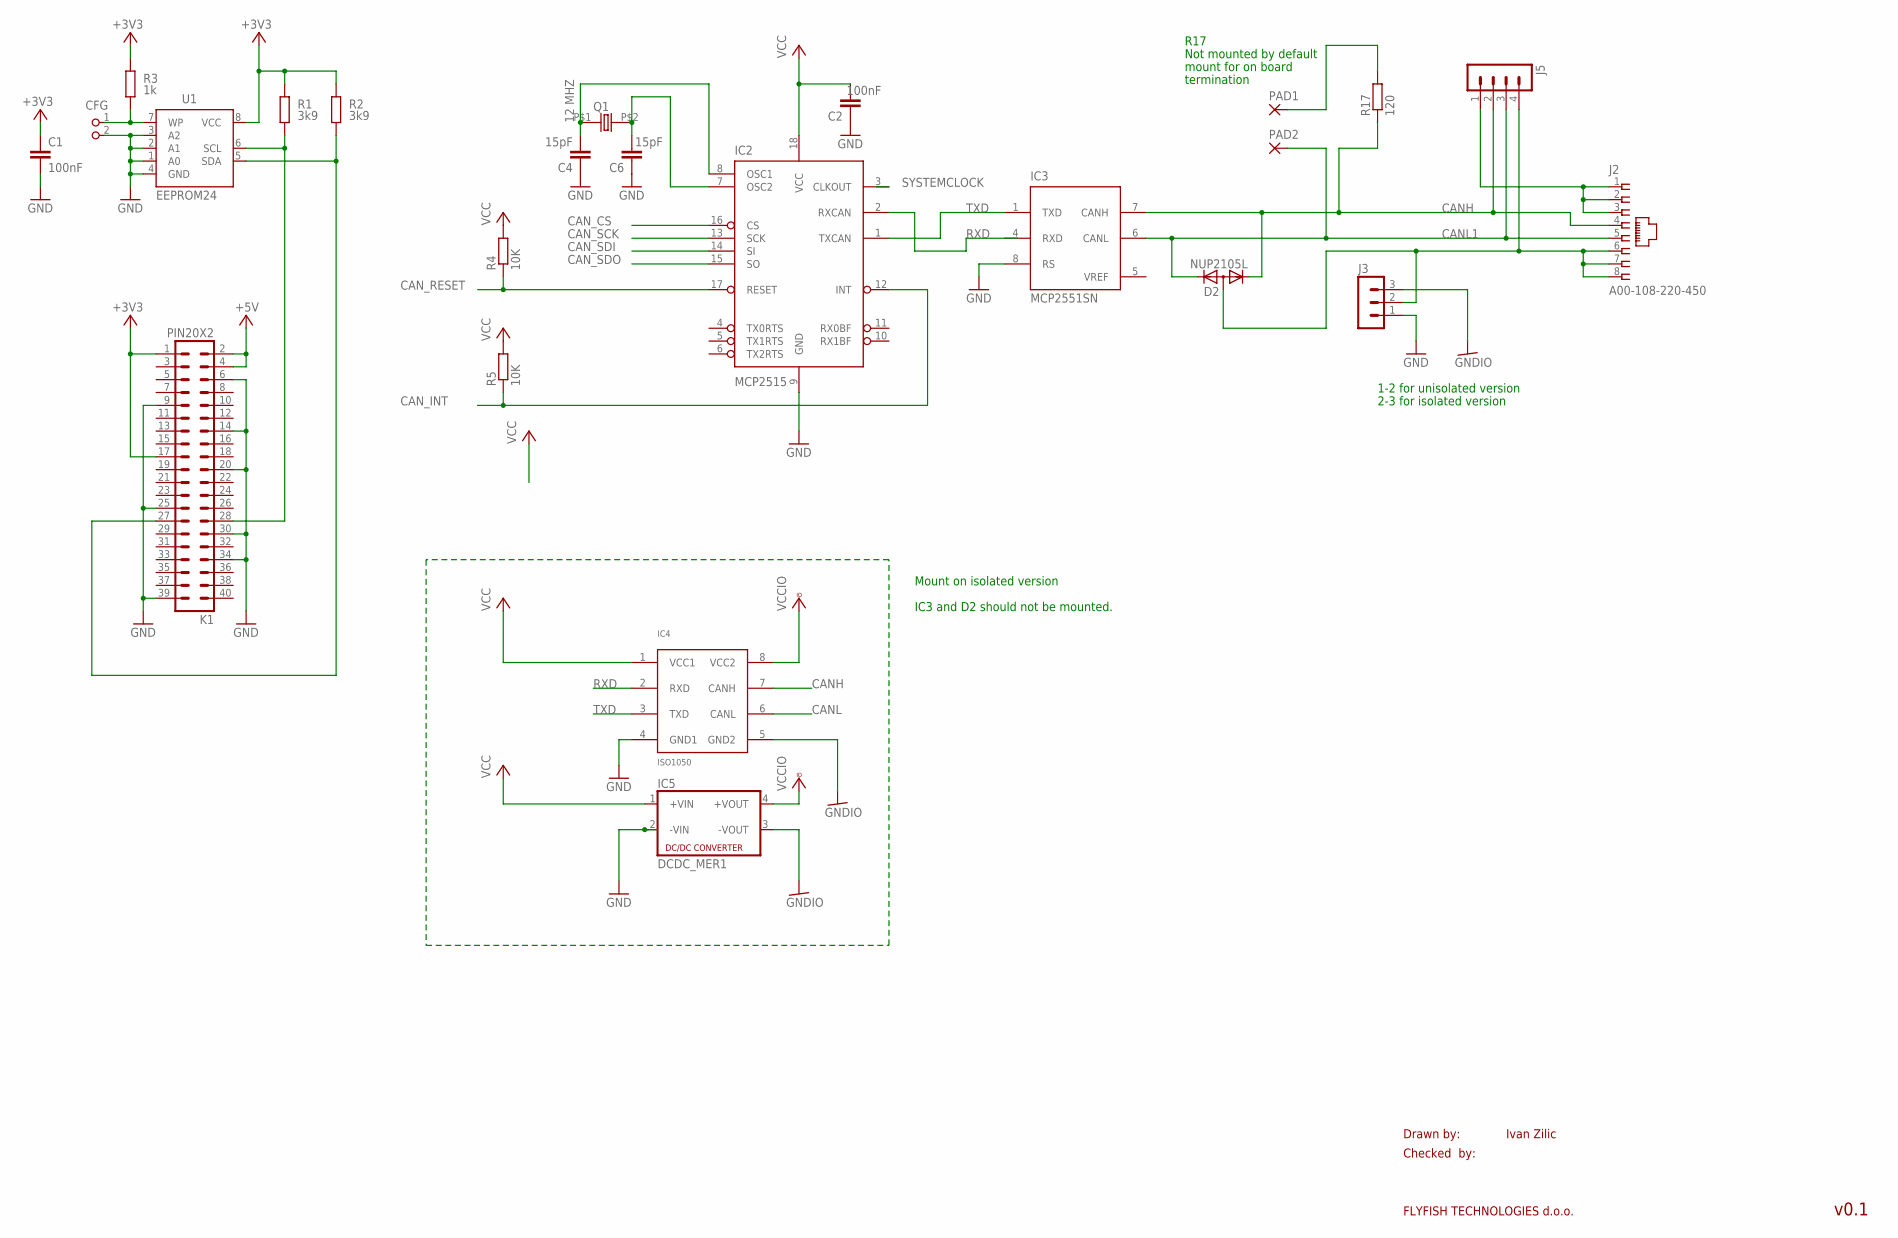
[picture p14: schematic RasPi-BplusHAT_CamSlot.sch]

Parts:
C1: 100nF; C0805K
C2: 100nF; C0805
C4, C6: 15pF; C0805
CFG: PIN2_100; PIN_W_2
D2: NUP2105L; SOT23
IC2: MCP2515; SO-18W
IC3: MCP2551SN; SO-08
IC4: ISO1050; DUB_PSOP
IC5: DCDC_MER1; MER1
J2: A00-108-220-450; RJ-45
J3: MA03-1
J5: MA04-1
K1: PIN20X2; PIN_20X2
PAD1, PAD2: 1,6/0,8
Q1: 12 MHZ; 9C
R1, R2: 3k9; M0805; TOLERANCE 5%
R3: 1k; M0805; TOLERANCE 5%
R4, R5: 10K; R0805
R17: 120; R0805
U1: EEPROM24; SOIC8

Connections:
+3V3: C1.1, K1.1, K1.17, R1.2, R2.2, R3.2, U1.8 (VCC)
+5V: K1.2, K1.4
CANH: D2.1 (K1), IC3.7 (CANH), IC4.7 (CANH), J2.4, J5.2, R17.1
CANL: IC4.6 (CANL)
CANL1: D2.2 (K2), IC3.6 (CANL), J2.5, J5.3, PAD2.1
CAN_CS: IC2.16 (CS)
CAN_INT: IC2.12 (INT), R5.1
CAN_RESET: IC2.17 (RESET), R4.1
CAN_SCK: IC2.13 (SCK)
CAN_SDI: IC2.14 (SI)
CAN_SDO: IC2.15 (SO)
GND: C1.2, C2.1, C4.1, C6.1, CFG.2, IC2.9 (GND), IC3.8 (RS), IC4.4 (GND1), IC5.2 (-VIN), J3.1, K1.6, K1.9, K1.14, K1.20, K1.25, K1.30, K1.34, K1.39, U1.1 (A0), U1.2 (A1), U1.3 (A2), U1.4 (GND)
GNDIO: IC4.5 (GND2), IC5.3 (-VOUT), J3.3
unnamed: K1.28, R1.1, U1.6 (SCL)
unnamed: K1.27, R2.1, U1.5 (SDA)
unnamed: CFG.1, R3.1, U1.7 (WP)
unnamed: C4.2, IC2.8 (OSC1), Q1.P$1 (1)
unnamed: C6.2, IC2.7 (OSC2), Q1.P$2 (2)
unnamed: D2.3 (A), J2.6, J2.7, J2.8, J3.2, J5.4
unnamed: PAD1.1, R17.2
unnamed: J2.1, J2.2, J2.3, J5.1
RXD: IC2.2 (RXCAN), IC4.2 (RXD)
SYSTEMCLOCK: IC2.3 (CLKOUT)
TXD: IC2.1 (TXCAN), IC3.1 (TXD), IC4.3 (TXD)
VCC: C2.2, IC2.18 (VCC), IC4.1 (VCC1), IC5.1 (+VIN), R4.2, R5.2
VCCIO: IC4.8 (VCC2), IC5.4 (+VOUT)
VDD: IC3.3 (VDD)
VREF: IC3.5 (VREF)
VSS: IC3.2 (VSS)

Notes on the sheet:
Drawn by:
Checked by:
FLYFISH TECHNOLOGIES d.o.o.
Ivan Zilic
v0.1
1-2 for unisolated version
2-3 for isolated version
Not mounted by default
mount for on board
termination
R17
Mount on isolated version
IC3 and D2 should not be mounted.

Board: 2 copper layers, 24 parts (0 on the bottom side), 20 nets, no tracks yet.

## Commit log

2015-08-28 Move from private to public
    [RasPi-BplusHAT.brd, RasPi-BplusHAT.sch, RasPi-BplusHAT_CamSlot.brd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]
2018-05-22 Make in sync
    [blitz_rev_C.brd, blitz_rev_C.sch, blitz_rev_D.brd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]
